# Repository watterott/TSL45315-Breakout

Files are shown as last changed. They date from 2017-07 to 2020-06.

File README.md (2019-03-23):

# TSL45315-Breakout
Breakout with AMS TSL4531 Digital Ambient Light Sensor.

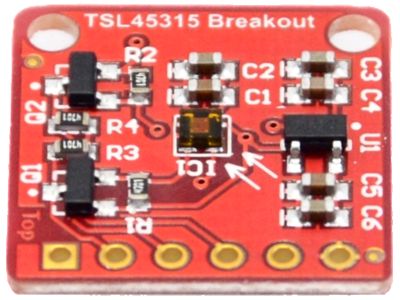
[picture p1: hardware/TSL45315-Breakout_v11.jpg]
TSL45315-Breakout


* [AMS TSL4531](https://ams.com/TSL45313) Light Sensor
* Direct lux output with wide dynamic range
* Range: 3 lux to 220k lux
* Rejects 50Hz/60Hz lighting ripple
* Approximates human eye response in diverse lighting conditions
* TWI/I2C Interface (address 0x29=TSL45315, 0x39=TSL45311)
* 3.3V - 5V Power Supply and Logic Level
* Open-Source and released under the [Creative Commons Attribution Share-Alike License](https://creativecommons.org/licenses/by-sa/4.0/).
* **[Documentation on learn.watterott.com](https://learn.watterott.com)**

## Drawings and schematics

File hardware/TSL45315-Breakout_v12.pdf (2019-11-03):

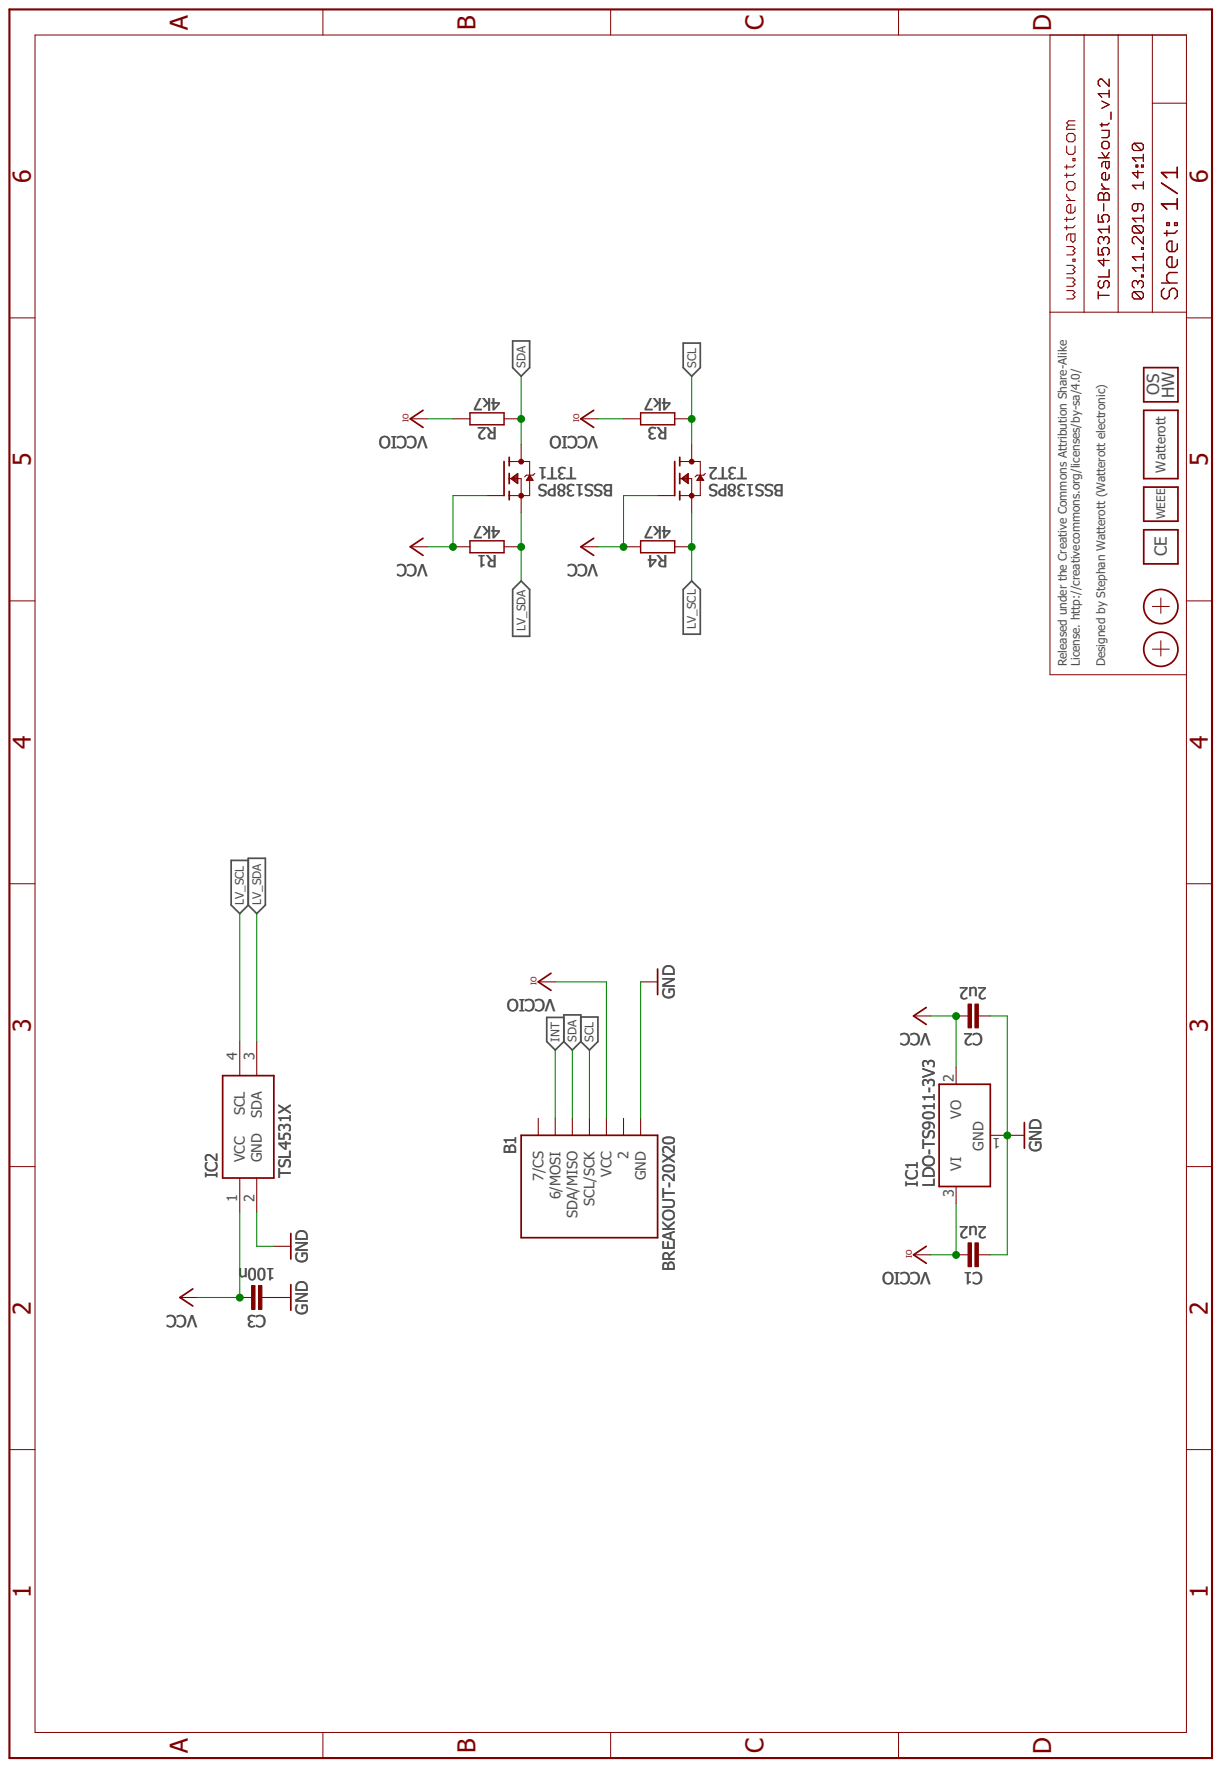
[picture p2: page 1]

Released under the Creative Commons Attribution Share-Alike

License. http://creativecommons.org/licenses/by-sa/4.0/ Designed by Stephan Watterott (Watterott electronic)

WEEE CE Watterott OS HW

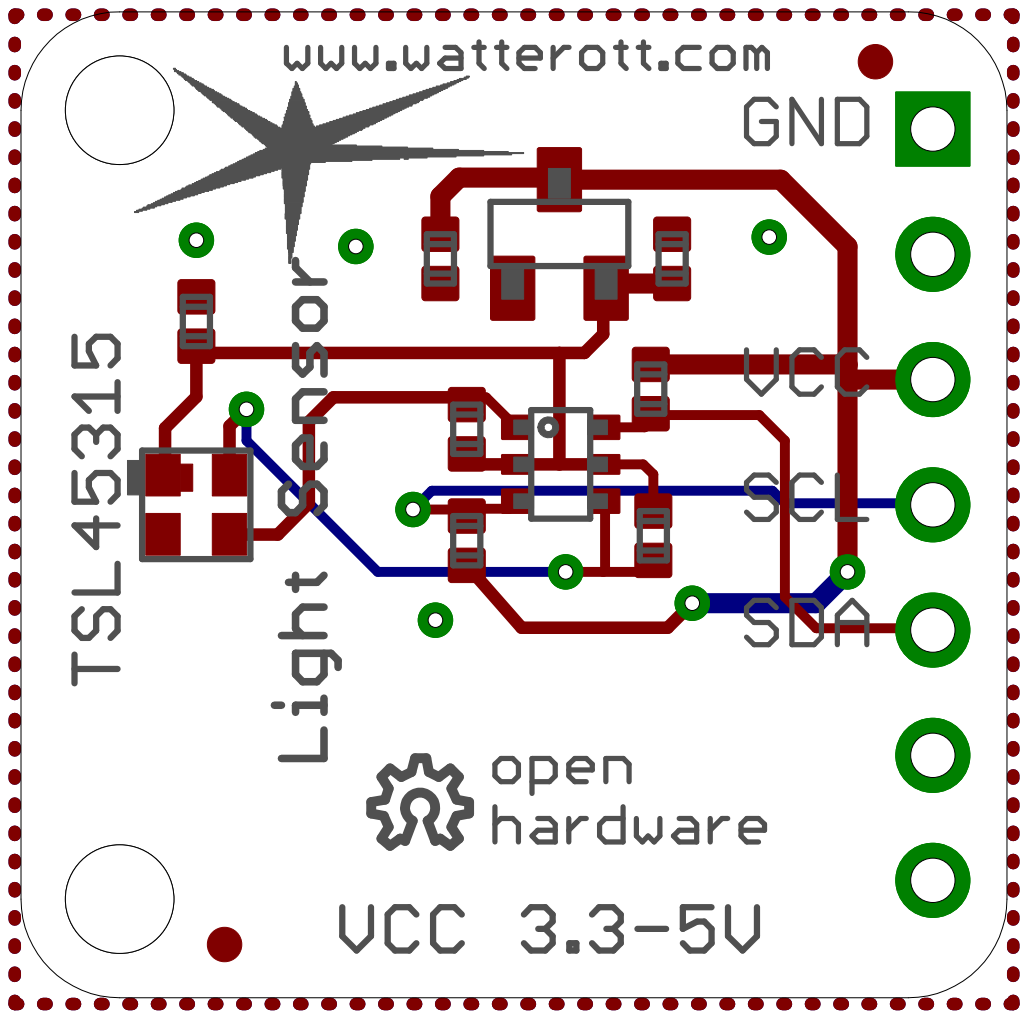
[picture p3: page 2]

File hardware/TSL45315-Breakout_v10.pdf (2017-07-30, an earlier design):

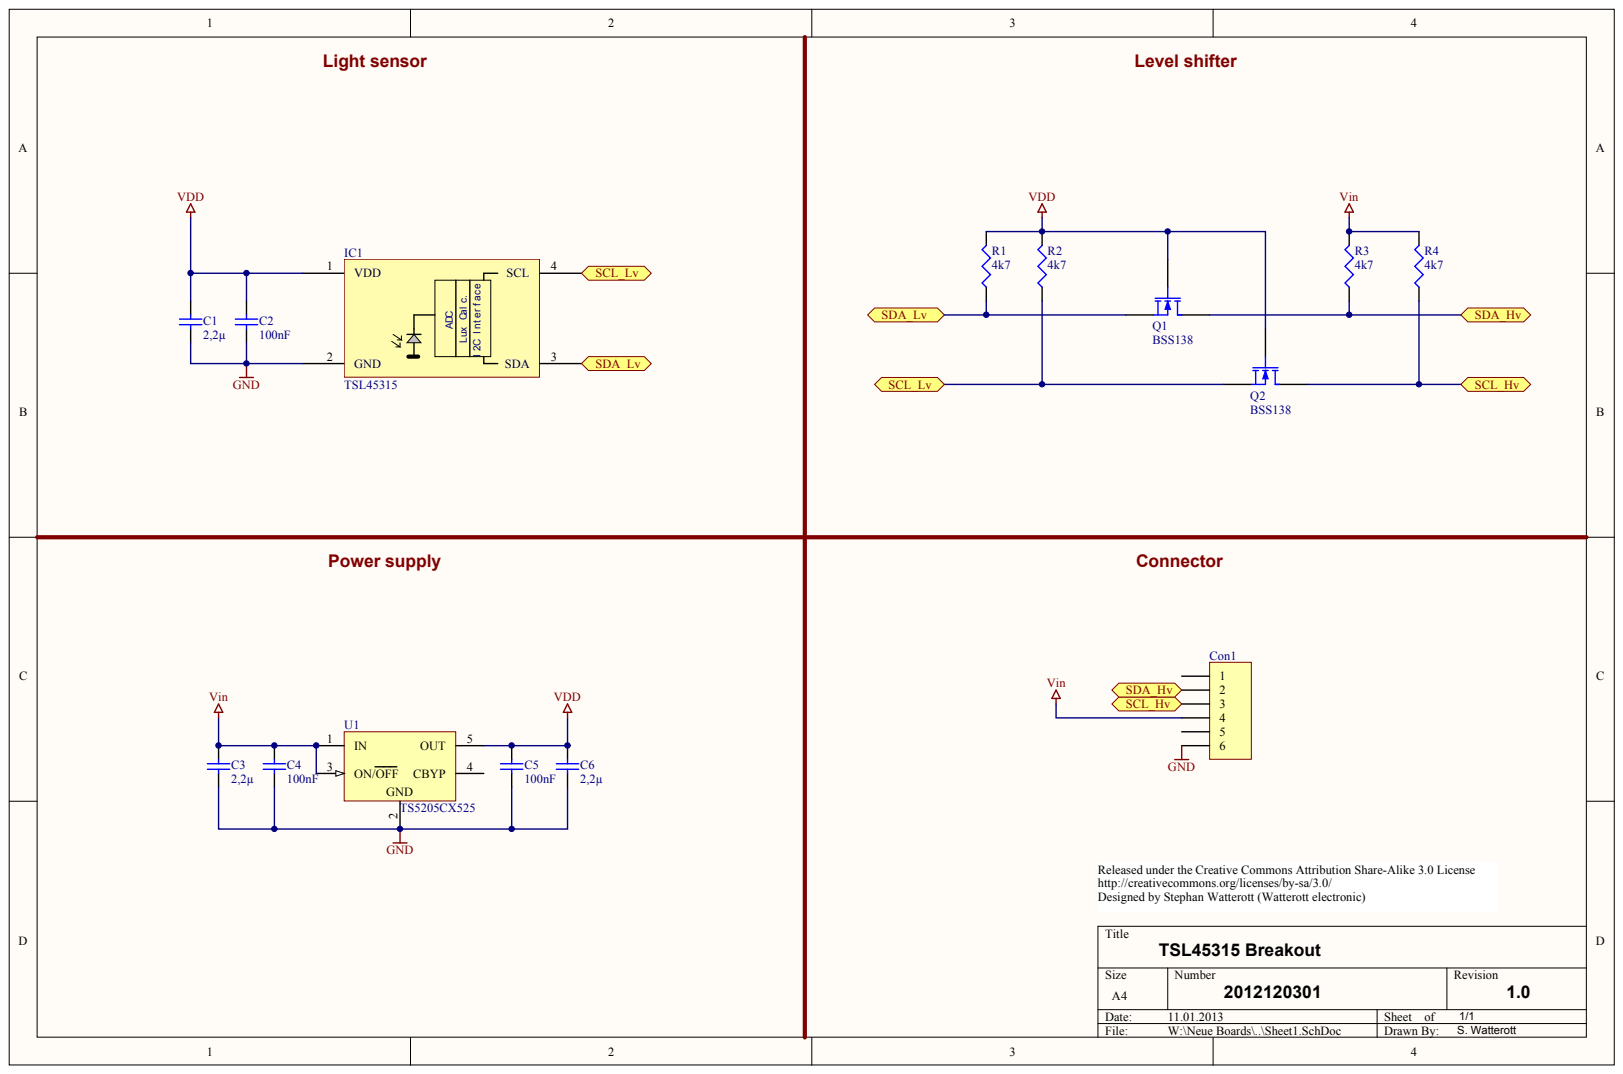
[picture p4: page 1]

C3 | C4
2,2µ | 100nF

GND

Released under the Creative Commons Attribution Share-Alike 3.0 License
http://creativecommons.org/licenses/by-sa/3.0/
Designed by Stephan Watterott (Watterott electronic)

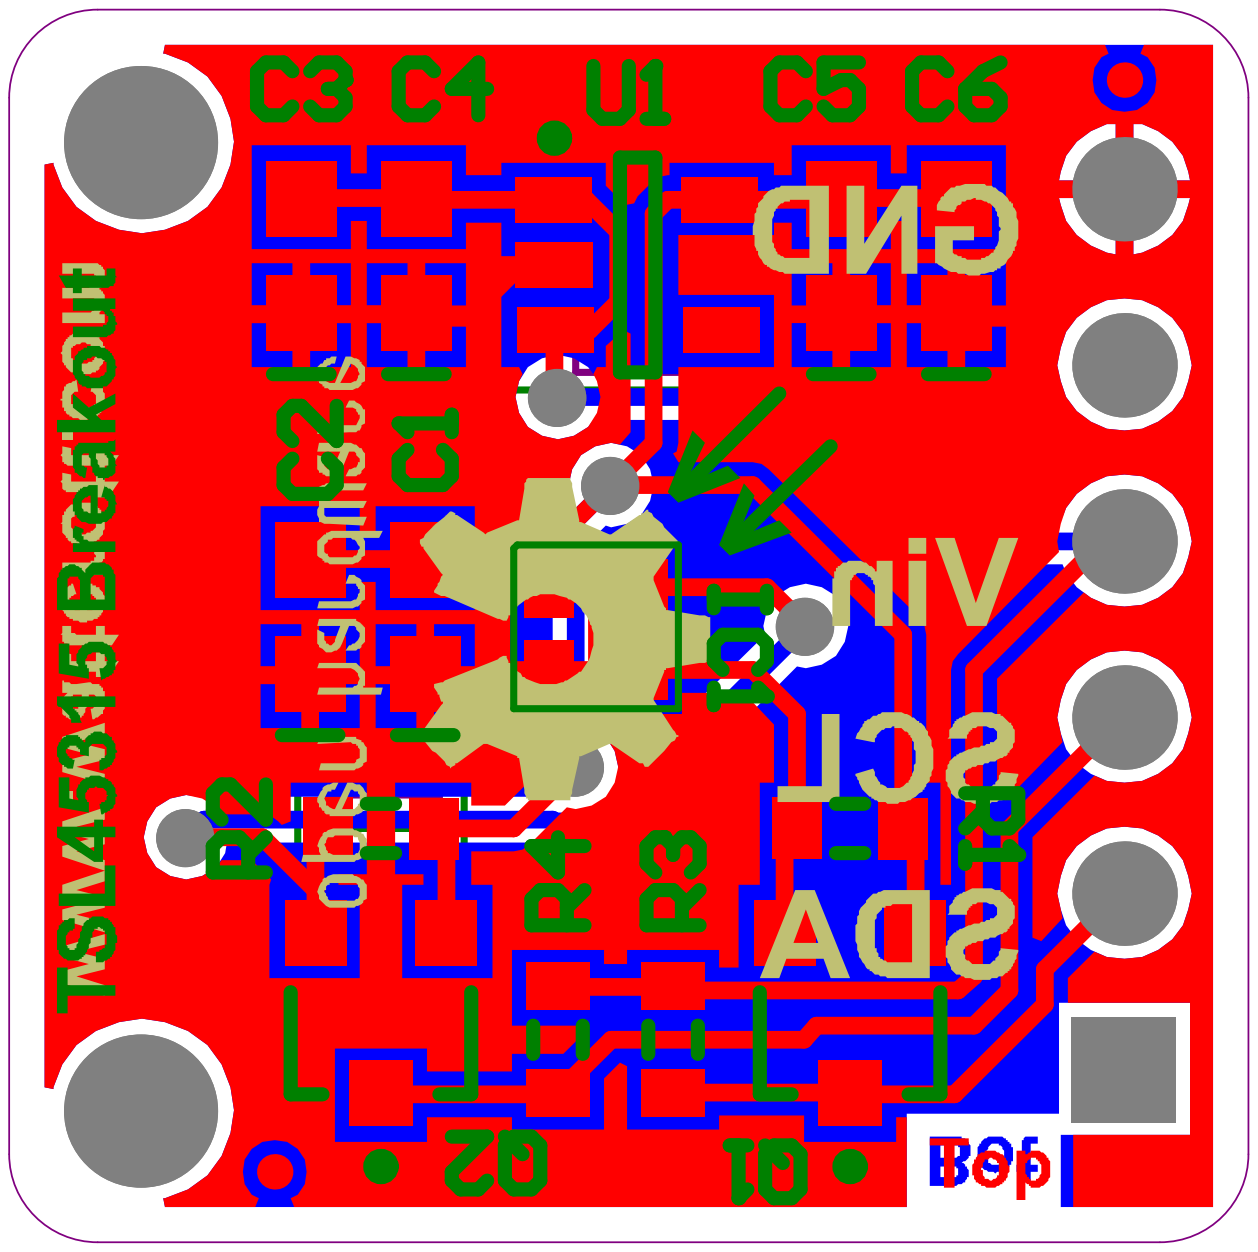
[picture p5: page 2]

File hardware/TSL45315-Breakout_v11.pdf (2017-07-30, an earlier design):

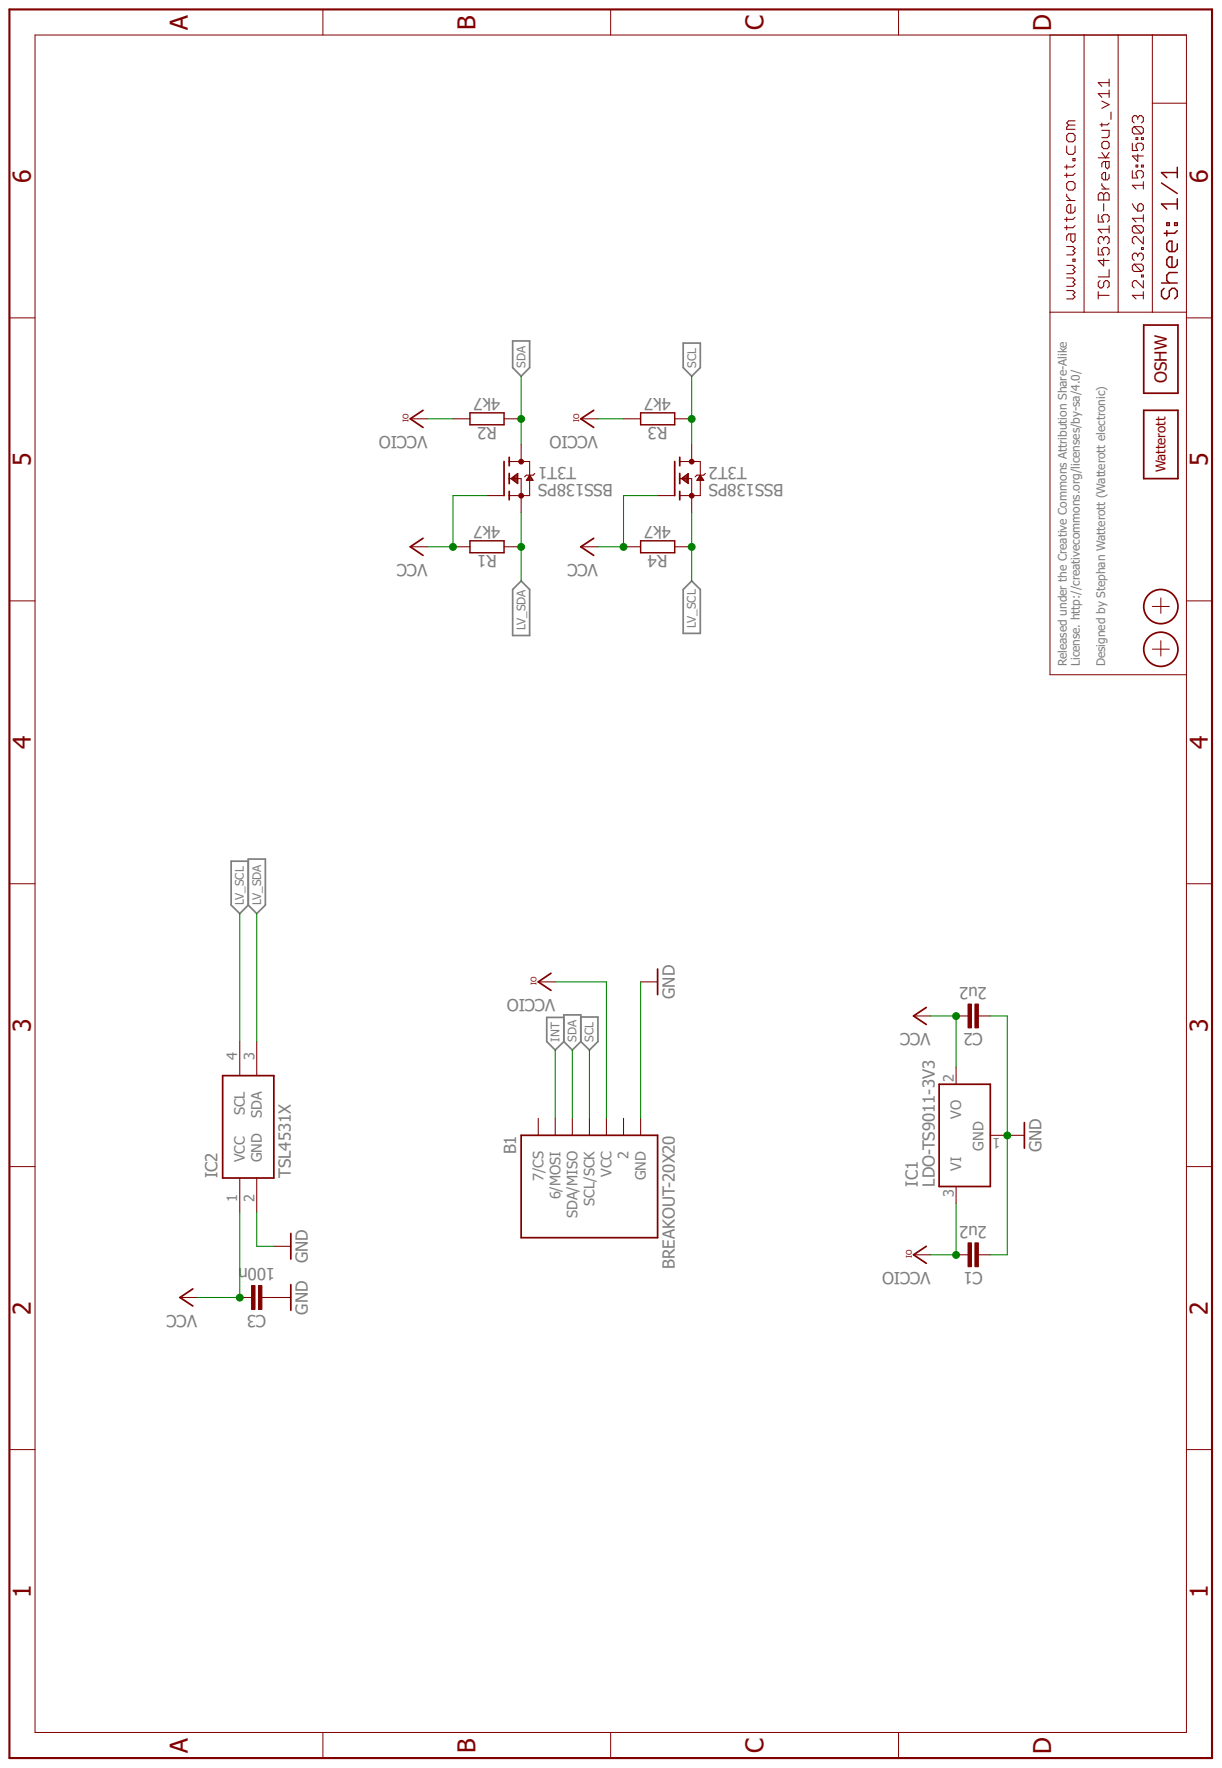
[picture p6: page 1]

Released under the Creative Commons At ribution Share-Alike

License. ht p://creativecommons.org/licenses/by-sa/4.0/ Designed by Stephan Wat erot (Wat erot electronic)

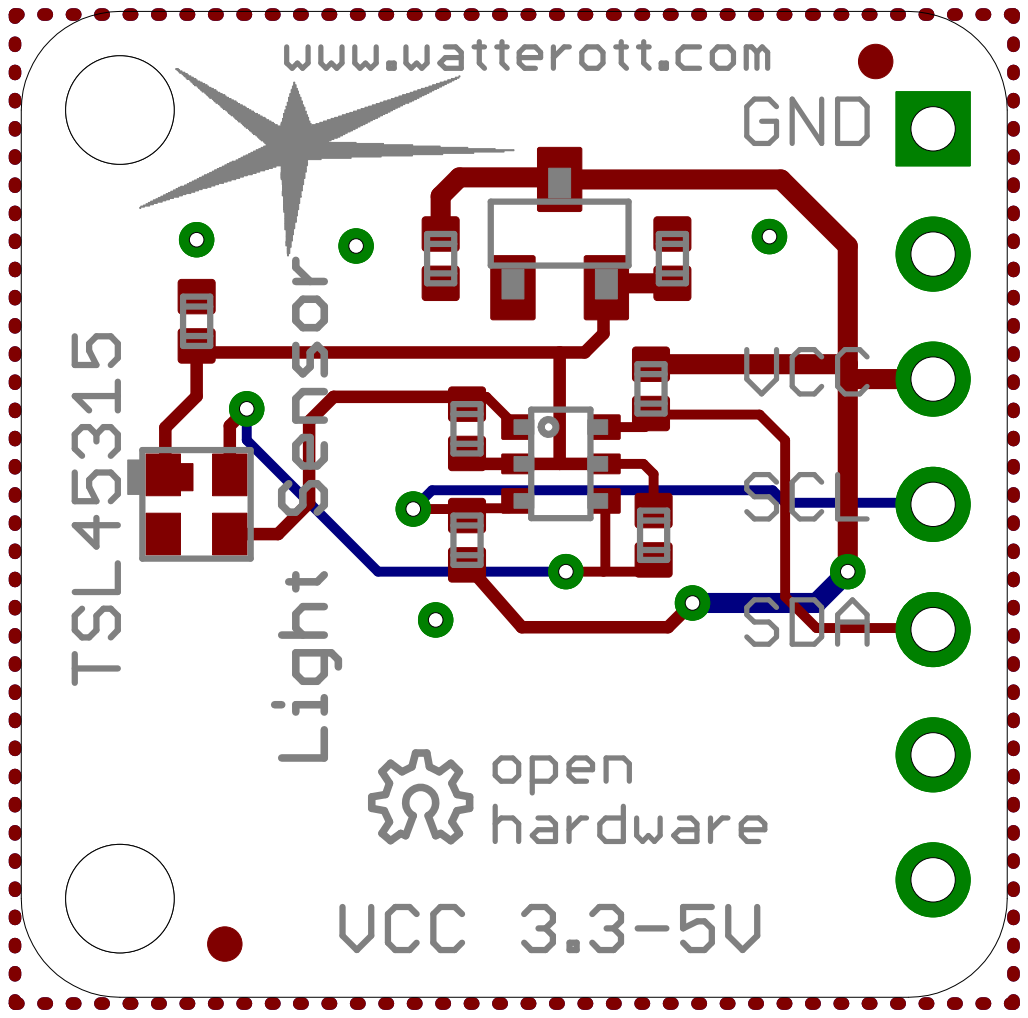
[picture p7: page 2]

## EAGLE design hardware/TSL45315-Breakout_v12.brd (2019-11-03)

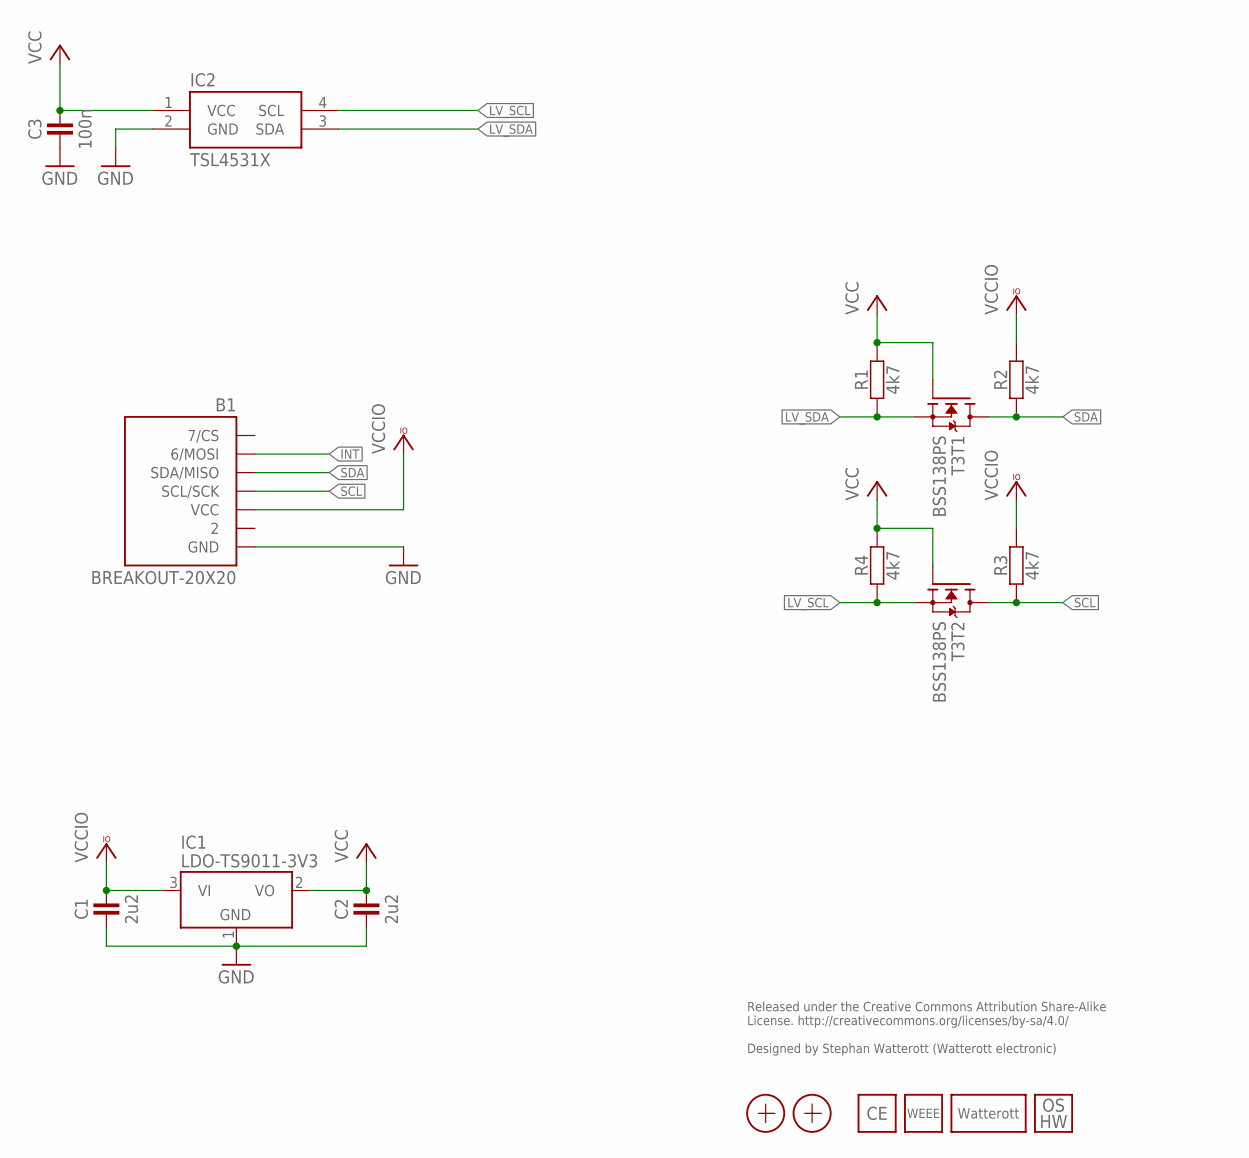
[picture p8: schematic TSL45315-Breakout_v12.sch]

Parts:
B1: BREAKOUT-20X20
C1, C2: 2u2; C0402
C3: 100n; C0402
IC1: LDO-TS9011-3V3; SOT23
IC2: TSL4531X; AMS_CL
LOGO3: LOGO_WEEE-4; WEEE_4MM
LOGO4: LOGO_CE-4; CE_4MM
LOGO5: LOGO_SPARK-4; SPARK_4MM
LOGO6: LOGO_OSHW-2; OSHW_2MM
R1, R2, R3, R4: 4k7; C0402
T3: BSS138PS; SOT363
X1, X2: PASSER-07; PASSER_07MM

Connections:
GND: B1.GND, C1.1, C2.1, C3.1, IC1.1 (GND), IC2.2 (GND)
INT: B1.MOSI (6/MOSI)
LV_SCL: IC2.4 (SCL), R4.1, T3.4 (S)
LV_SDA: IC2.3 (SDA), R1.1, T3.1 (S)
SCL: B1.SCL/SCK, R3.1, T3.3 (D)
SDA: B1.SDA/MISO, R2.1, T3.6 (D)
VCC: C2.2, C3.2, IC1.2 (VO), IC2.1 (VCC), R1.2, R4.2, T3.2 (G), T3.5 (G)
VCCIO: B1.VCC, C1.2, IC1.3 (VI), R2.2, R3.2

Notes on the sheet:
Released under the Creative Commons Attribution Share-Alike License. http://creativecommons.org/licenses/by-sa/4.0/ Designed by Stephan Watterott (Watterott electronic)

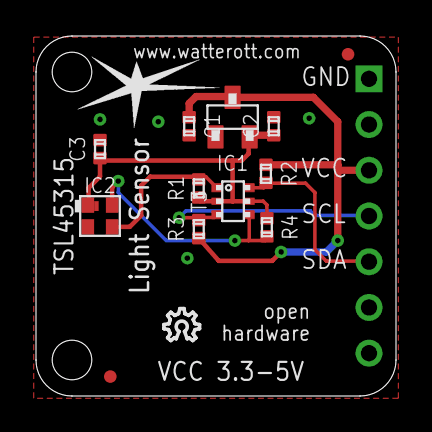
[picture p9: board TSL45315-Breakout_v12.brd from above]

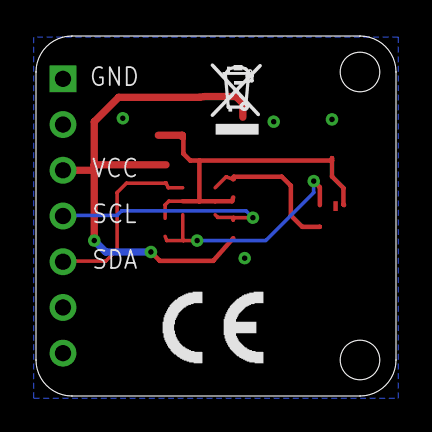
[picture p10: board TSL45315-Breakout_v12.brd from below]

Board: 2 copper layers, 20.0 x 20.0 mm, 17 parts (2 on the bottom side), 7 nets.

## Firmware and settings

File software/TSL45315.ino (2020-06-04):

/*
  Example sketch for TSL45315-Breakout (Digital Ambient Light Sensor).

  Board           I2C/TWI Pins
                  SDA, SCL
  ----------------------------
  Uno, Ethernet    A4, A5
  Mega             20, 21
  Leonardo          2,  3
  Due              20, 21

  Example source code free to use.
  Further information: https://learn.watterott.com/license/
*/

#include <Wire.h>

#define I2C_ADDR     0x29

#define REG_CONTROL  0x00
#define REG_CONFIG   0x01
#define REG_DATALOW  0x04
#define REG_DATAHIGH 0x05
#define REG_ID       0x0A

void setup()
{
  Serial.begin(9600);
  while(!Serial); //wait for serial port to connect (needed for Leonardo only)

  Wire.begin();

  Serial.print("ID: ");
  Wire.beginTransmission(I2C_ADDR);
  Wire.write(0x80|REG_ID);
  Wire.endTransmission();
  Wire.requestFrom(I2C_ADDR, 1); //request 1 byte
  while(Wire.available())
  {
    unsigned char c = Wire.read();
    Serial.print(c&0xF0, HEX);
  }
  Serial.println("");

  Serial.println("Power on...");
  Wire.beginTransmission(I2C_ADDR);
  Wire.write(0x80|REG_CONTROL);
  Wire.write(0x03); //power on
  Wire.endTransmission();

  Serial.println("Config...");
  Wire.beginTransmission(I2C_ADDR);
  Wire.write(0x80|REG_CONFIG);
  Wire.write(0x00); //M=1 T=400ms
  // Wire.write(0x01); //M=2 T=200ms
  // Wire.write(0x02); //M=4 T=100ms
  Wire.endTransmission();
}

void loop()
{
  uint16_t l, h;
  uint32_t lux;

  Wire.beginTransmission(I2C_ADDR);
  Wire.write(0x80|REG_DATALOW);
  Wire.endTransmission();
  Wire.requestFrom(I2C_ADDR, 2); //request 2 bytes
  l = Wire.read();
  h = Wire.read();
  lux  = (h<<8) | (l<<0);
  lux *= 1; //M=1
  // lux *= 2; //M=2
  // lux *= 4; //M=4
  Serial.print("Lux: ");
  Serial.println(lux, DEC);

  delay(1000);
}

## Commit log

2019-11-03 added rev 1.2
    [TSL45315-Breakout_v12.brd, TSL45315-Breakout_v12.sch]
2020-06-03 No need to clear the buffer after a Wire.requestFrom.
    Explanation: https://github.com/Koepel/How-to-use-the-Arduino-Wire-library/wiki/Common-mistakes#4
    Beside that, when the Master call Wire.requestFrom to requests 2 bytes, then it is impossible that it will have more than two bytes.
    [TSL45315.ino]
